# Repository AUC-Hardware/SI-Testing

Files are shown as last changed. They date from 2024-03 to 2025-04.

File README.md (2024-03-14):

# SI-Testing

> Spring 2024, Dr. Shalan

**Goal:** is to provide a circuit capable of testinga chip under changing voltage and temperature. 
- for temperature, we are using a thermoelectric cooler. as a *sub goal* we need to supply with an ideal controlling (PWM) signal to be able to vary the temperature rapidly

---

### Raspberry Pi Pico W

Getting Started: https://projects.raspberrypi.org/en/projects/getting-started-with-the-pico/1

Documentation: https://www.raspberrypi.com/documentation/microcontrollers/raspberry-pi-pico.html

#### Pinout Diagram


Our digital Microcontroller
- Will host ``micropython`` code to execute and control the circuitry
  - The code will have the PID which controlls the PWM signal 

---
### Relay Switch : To be documented

Datasheet:

- is used to protect the Pico from the Temperature varying circuitry
- The PWM signal is suppled to it

---
### Peltier : TEC1-12706

Datasheet: https://www.alldatasheet.com/datasheet-pdf/pdf/227422/ETC2/TEC1-12706.html
> A better datasheet or reference is needed

Thermoelectric cooler
- is used to cary the temperature on the chip
- $12V$, $6A$
- switches heating and cooling sides when current direction is switched 

---
### Digital Potentiometer : MCP4131-103E/P

Datasheet: https://u.pcloud.link/publink/show?code=XZEJx00Z2zHjB7IoRRXOGcCnvikJS4BVzfdy

Volatile Memory Digital Potentiometer
- Is used to vary the voltage on the chip
- Has memory to remember the latest resistance setting

---
### Second Digital Potentiometer : X9C103S

Datasheet: [https://u.pcloud.link/publink/show?code=XZEJx00Z2zHjB7IoRRXOGcCnvikJS4BVzfdy](https://u.pcloud.link/publink/show?code=XZcJRX0ZARyeeIvch2VLE2VBvFsLeyBOw4zV)
Example: https://electropeak.com/learn/interfacing-x9c103s-10k-digital-potentiometer-module-with-arduino/

- Is used to vary the voltage on the chip
- 0-10kΩ with 100 steps
- Up to ±5V across the potentiometer end-points

---
### Temperature Sensor : DS18B20 Waterproof Temperature Sensor

Datasheet: https://u.pcloud.link/publink/show?code=XZfujk0ZSR5hogIrCKkFY19oXnh8zp0lHThX

- Will provide temperature input to the PICO from the Thermoelectric cooler to be given to the PID

---
### Thermometer : TP101 

Datasheet: https://u.pcloud.link/publink/show?code=XZfujk0ZSR5hogIrCKkFY19oXnh8zp0lHThX

- Measuring Temperature Range: -50 to 300 degrees (-58 to 572 Fahrenheit)

---
### Thermometer with probe: TPM-10  

Datasheet: https://u.pcloud.link/publink/show?code=XZfujk0ZSR5hogIrCKkFY19oXnh8zp0lHThX

- Temperature range: -50°C~ 110°C
- Temperature accuracy: ±1°C
- Resolution: 0.1°C

---
### Voltage Regulator: LM317

Datasheet: https://u.pcloud.link/publink/show?code=XZqG0X0ZURodwRRACp8z1VfRVn5GCHM6Uq97

It will be used to assist with voltage control. See the voltage control circuit diagram for more details

---

>[!NOTE] 
>
> Optional circuitry \
> **High Power Resistor**
> - is used to reduce current on the thermoelectric cooler if normal operating current is too high for our need 
> 
> **H-Bridge** 
> - mainly for experimentation 
> - is used to be able to switch the polarity on the thermoelectric cooler so we could switch cooling and heating

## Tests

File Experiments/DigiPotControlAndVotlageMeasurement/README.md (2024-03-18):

Goal was to control Digital Pot according to some condition on the voltage measured
Condition was to break once a certain threshold of voltage was reached

Voltage change was observed with a multimeter and was visually verified by a simple LED.

## Circuit Diagram:



>[!note]
>
> The LED was also fitted in place of the voltage divider (the two resistors)

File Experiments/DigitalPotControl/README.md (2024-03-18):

# Digital Control of X9C103S POT

Aim is to Digitally control the POT and exploring its functionality
The POT has the following control signals,

## Circuit 

Digital_Pot_Control_bb

Skip to [Key Takeaways](#key-takeaways) for a TLDR of X9C103S control.

## Symbol Descriptions

`U/~D` Up Down, control direction of wiper movement

`~INC` increment, negative edge triggered toggling whether wiper will increment or decrement depending on logic of the `U/D` input.

`~CS`Chip Select, Current Counter Value is stored in nonvolatile memory. Once stored the device is put into low power standby until the digital pot control is selected once again.

$V_w$ Wiper output

$V_l$ Low voltage

$V_H$ high voltage

## Mode Selection 

| ~CS| ~INC | U/~D | Mode |
| --- | --- | --- | --- |
| L | Negative Edge | H | Wiper Up |
| L | Negative Edge | L | Wiper Down | 
| Positive Edge | H | X | Store Wiper Position | 
| H | X | X | Standby Current | 
| Positive Edge | L | X | No Store, Return to Standby | 

>[!warning]
>
>Supply Voltage Operational Limits:  $5V\ \pm 10$%

## IMPORTANT: Timings

| Parameter | Min | Typ | Max | Units |
| --- | --- | --- | --- | --- |
| CS to INC setup | 100 | | | ns |
| INC HIGH to U/D change | 100 | | | ns |
| U/D to INC setup | 2.9 | | | $\mu s$ |
| INC LOW period | 1 | | | $\mu s$ | 
| INC HIGH period | 1 | | | $\mu s$ |
| INC Inactive to CS Inactive | 1 | | | $\mu s$ |
| CS deselect time | 20  | | | ms |
| INC to $V_w$ Change | | 100 | 500 | $\mu s$ |
| INC Cycle Time | 4 | | | $\mu s$ |
| INC Rise and Fall Time | | | 500 | $\mu s$ |
| Power Up to Wiper Stable | | | 500 | $\mu s$ |
| $V_{cc}$ Power up Rate | 0.2 | | 50  | $\frac{mV}{\mu S}$|

### Key Takeaways

Operational Voltages
- HIGH: `INC`,`CS`, `U\D` Min: 2V, MAX: VCC + 1
- LOW: `INC`,`CS`, `U\D` Min: -1V, MAX: 0.8

Operational Current
- $I_{CC}$, $V_{CC}$ Active Current, TYP: 1 mA, MAX: 3mA 

#### Wiper Control
Wiper Increments in $101\Omega$
Min Resistance $40\Omega$
Max Resistance $10k\Omega$

Control Signal Timings:
- A sleep for $500 \mu s$ is needed to stabilise the wiper, see ``utimer`` lib for MicroPython
- Changing any of the ``~INC``, ``U/~D`` signals need to occur within $>100ns$ 
- ``INC`` Periods need to last at least for $1 \mu s$
- Any Change to ``U/~D`` is accompanied by a sleep of $2.9 \mu s$
- Maximum Pulse Rate (Cycle time) for ``INC`` is $4 \mu s$

#### Non-Voltatile memory handling

- Any Change to `~CS` needs to last $> 20 ms$ 
- Any Change to ``INC`` after changing `~CS` need to have $100 ns$ delay between them

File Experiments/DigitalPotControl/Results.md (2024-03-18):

- LED gradually goes up in brightness and gradually decreased in brightness

### Important notes

On the Osilliscope the resulting square wave generated from iterating on `blink()` function had a bigger cycle time than expected.

We should change the use of `time` lib and utilise the use of the RP2 assembly to have acute control over the delay.

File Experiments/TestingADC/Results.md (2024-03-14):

# PicoADCTest

## Description

This was a simple experiment to test the PICO's ability to read an analog signal that ranges from 0 to 3.3V  (due to using the PICO's Vcc)

ADC has a 12-bit resolution, which means a range from 0 to 4095
In micro python this is mapped to a 16-bit value, which means the code wise it will range from 0 to 65535

## Method

Using ADC on pin 31 (GP 26), read voltage across a 10k Ohm mechanical potentiometer and compare readings to that of a multimeter.

## Results

PICO was able to accuratly read voltage such that it always matched the readings on our digital multimeter ( the M890G ).

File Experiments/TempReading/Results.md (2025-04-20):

# DS18B20 Temprature reading experiment

## Description

This was a simple experiment to test the reading of the temprature from the DS18B20 temprature sensor to the pico microcontroller.

## Method

The libraries used was the onewire library and the DS18x20 library. Together, we are able to interface our DS18B20 device and read temprature from it. The pin used to read temprature was PIN 15, which was connected to the DQ on the temprature sensor. VDD was supplied from the pico as 3.3V and GND was also from the pico.

## Results

PICO was able to accuratly read temprature.

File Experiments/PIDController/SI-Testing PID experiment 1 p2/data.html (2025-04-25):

| A | B | C | D | E | F | G | H
1 | PID Out | | Time 40ms | Measured Temperature | Set point | | Parameters Used | Parameter Value
2 | 38.9898 | | 1 | 30 | 40 | | Kp | 1
3 | 38.99355 | | 2 | 30 | 40 | | Ki | 2
4 | 42.30204 | | 3 | 30 | 40 | | Kd | 1
5 | 47.70129 | | 4 | 30 | 40
6 | 53.92326 | | 5 | 30 | 40 | | Sampling rate (seconds) | 0.45
7 | 52.48206 | | 6 | 30 | 40 | | tau | 1
8 | 51.57029 | | 7 | 30 | 40
9 | 50.99345 | | 8 | 30 | 40 | | integral anti windup max value | -50
10 | 50.62851 | | 9 | 30 | 40 | | integral anti windup min value | 50
11 | 50.39762 | | 10 | 30 | 40
12 | 50.25156 | | 11 | 30 | 40 | | Starting PID output | 23
13 | 50.15915 | | 12 | 30 | 40
14 | 50.10069 | | 13 | 30 | 40
15 | 50.0637 | | 14 | 30 | 40
16 | 50.0403 | | 15 | 30 | 40 | | Max Oscillation Temp | 42.6875
17 | 50.0255 | | 16 | 30 | 40 | | Min Oscillation Temp | 39.0625
18 | 50.01613 | | 17 | 30 | 40
19 | 50.0102 | | 18 | 30 | 40
20 | 50.00645 | | 19 | 30 | 40
21 | 49.90204 | | 20 | 29.875 | 40
22 | 49.93803 | | 21 | 29.875 | 40
23 | 49.96079 | | 22 | 29.875 | 40
24 | 49.9752 | | 23 | 29.875 | 40
25 | 49.98431 | | 24 | 29.875 | 40
26 | 49.99007 | | 25 | 29.875 | 40
27 | 49.99372 | | 26 | 29.875 | 40
28 | 49.99603 | | 27 | 29.875 | 40
29 | 49.99749 | | 28 | 29.875 | 40
30 | 49.99841 | | 29 | 29.875 | 40
31 | 49.99899 | | 30 | 29.875 | 40
32 | 49.99936 | | 31 | 29.875 | 40
33 | 49.9996 | | 32 | 29.875 | 40
34 | 49.99974 | | 33 | 29.875 | 40
35 | 49.99984 | | 34 | 29.875 | 40
36 | 49.9999 | | 35 | 29.875 | 40
37 | 49.99994 | | 36 | 29.875 | 40
38 | 49.99996 | | 37 | 29.875 | 40
39 | 49.99997 | | 38 | 29.875 | 40
40 | 49.99998 | | 39 | 29.875 | 40
41 | 49.99999 | | 40 | 29.875 | 40
42 | 49.99999 | | 41 | 29.875 | 40
43 | 50 | | 42 | 29.875 | 40
44 | 50 | | 43 | 29.875 | 40
45 | 50 | | 44 | 29.875 | 40
46 | 50 | | 45 | 29.875 | 40
47 | 50 | | 46 | 29.875 | 40
48 | 50 | | 47 | 29.875 | 40
49 | 50 | | 48 | 29.875 | 40
50 | 50 | | 49 | 29.875 | 40
51 | 50 | | 50 | 29.875 | 40
52 | 50 | | 51 | 29.875 | 40
53 | 50 | | 52 | 29.875 | 40
54 | 50 | | 53 | 29.875 | 40
55 | 50 | | 54 | 29.875 | 40
56 | 50 | | 55 | 29.875 | 40
57 | 50 | | 56 | 29.875 | 40
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

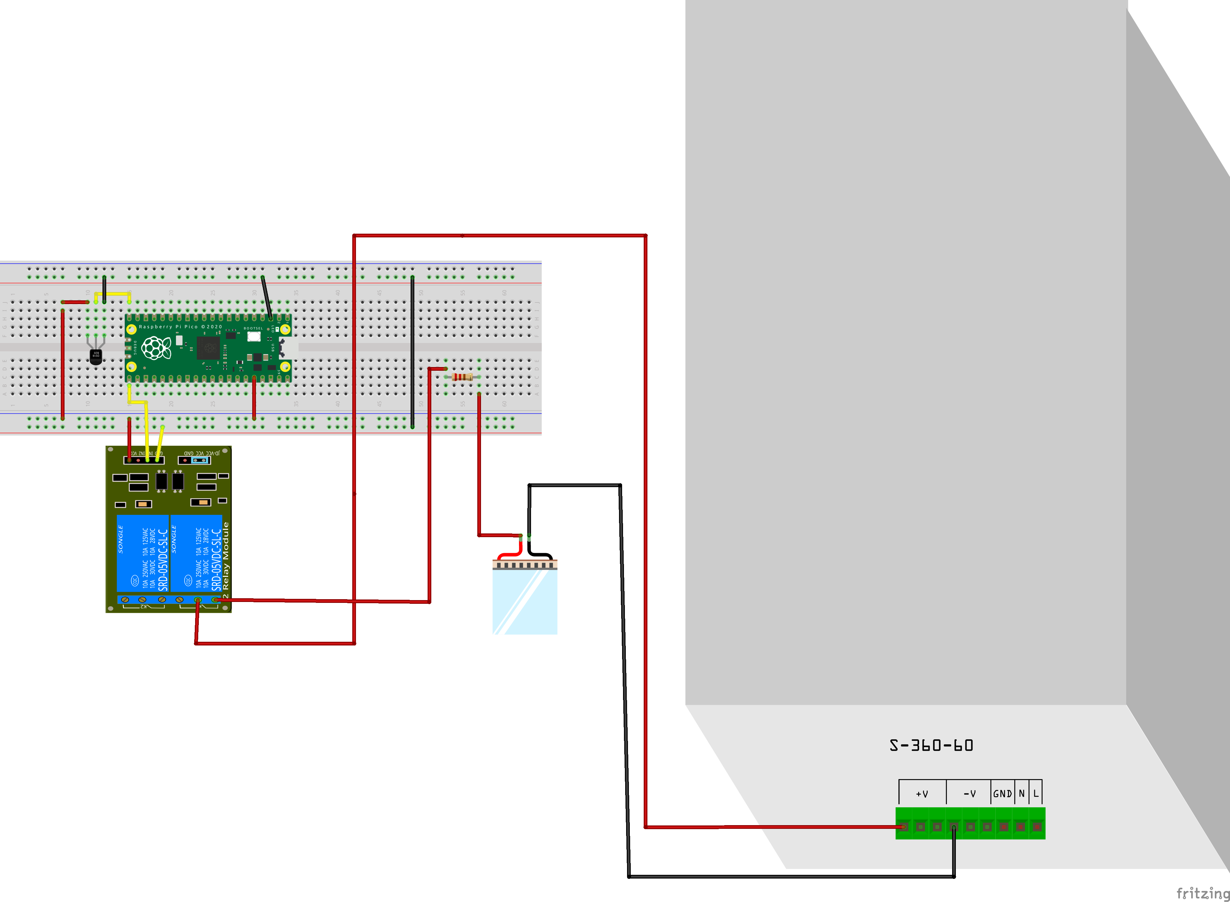
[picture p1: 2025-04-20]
Experiments/Temp_reading_relay_loop/relay_peltier_tempsensor_loop.png

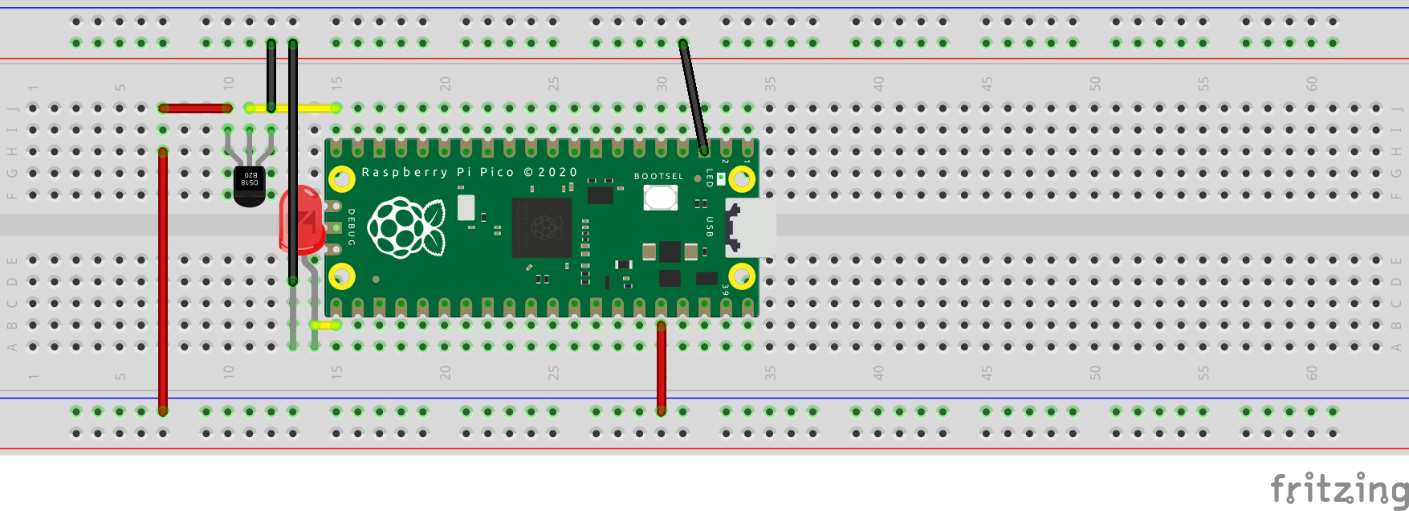
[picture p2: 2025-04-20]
Experiments/TempReading/Temprature_reading_DS18B20_diagram.png

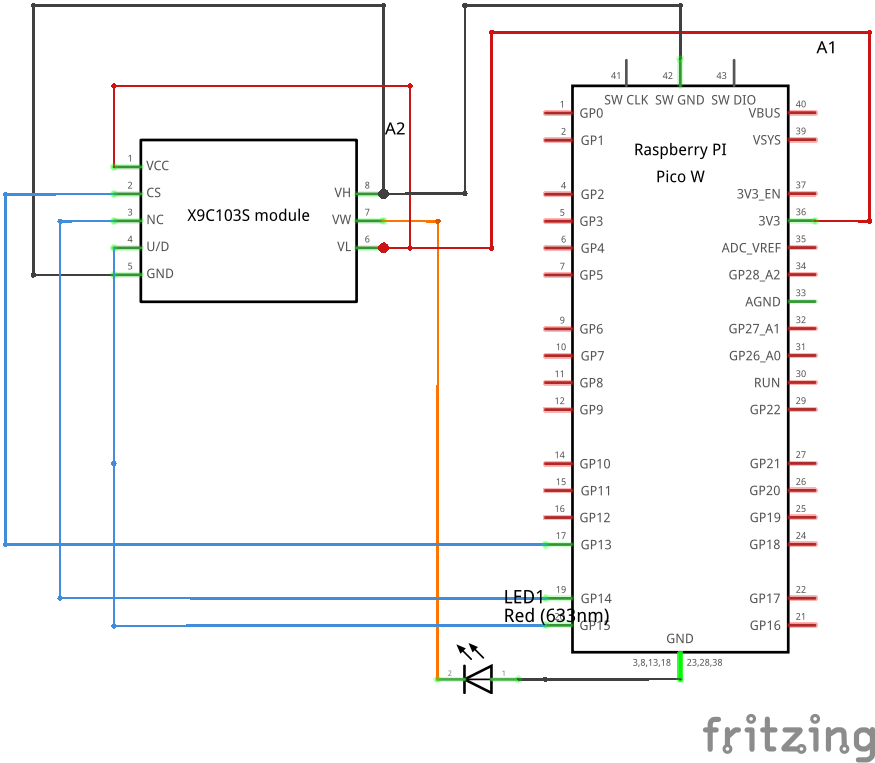
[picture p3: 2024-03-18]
Experiments/DigitalPotControl/Digital_Pot_Control_schem.png

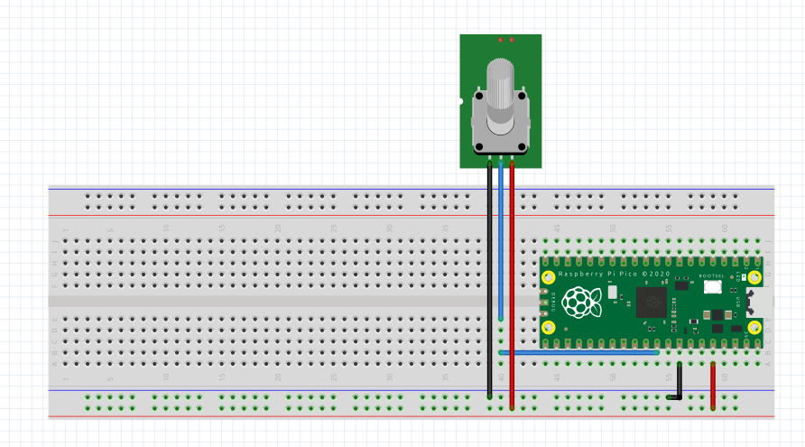
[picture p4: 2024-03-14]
Experiments/TestingADC/PicoADCTest.png

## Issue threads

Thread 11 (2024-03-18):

Complete Digital Signal Control using RP2 Assembly

Ahmed-Waseem77, 2024-03-18:
uncovered in issue #8

---

When generating signals any two successive toggles for a PIO pin has about 20 us ON (or OFF) period, (This was verified with an oscilloscope).

For our use case we would need greater control in ns scale for greater efficiency thus the need for RP2 assembly digital signal controllers.

Goal is to construct a general class or a function for digital signal generation in us.
RP2 has around 125MHZ so the cycle takes around 8ns.

shalan, 2024-03-18:
Not sure about the need for this.
The process we are controlling is slow; there is no need for us DIO resolution.

Ahmed-Waseem77, 2024-03-21:
Noted, closing the issue!

Closed 2024-03-21.

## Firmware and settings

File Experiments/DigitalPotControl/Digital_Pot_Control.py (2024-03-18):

from machine import Pin
import time
import rp2

# CS to INC setup
def tci():
    time.sleep_ms(5)

# UD to INC setup
def tdi():
    time.sleep_us(5)

# INC High to UD change
def tid():
    time.sleep_us(5)
    
# INC High and Low period
def tihl():
    #5 microseconds
    time.sleep_us(5)

# chip select
cs = Pin(14,mode=Pin.OUT,value=0)
tci()

# up down
ud = Pin(13,mode=Pin.OUT,value=1)
tdi()

# increment
inc = Pin(12,mode=Pin.OUT,value=1)
tid()


# This yields a pulse of 35 us which is counter intuitive
# for the time being this suits our use case
# TODO: change this into rp2 assembly instructions
def blink(pin):
    pin.toggle()
    tihl()
    
def wiperControl(increments,updownSelect):
    ud.value(updownSelect)
    tdi()
    for i in range(0,increments):
        time.sleep_ms(2)
        blink(inc)
        
        
#10k ohms and 101ohm step
#100 increments to max/min
#for some odd reason, it maxes out at ~110 not 100
while True:
    wiperControl(110,1)
    wiperControl(110,0)

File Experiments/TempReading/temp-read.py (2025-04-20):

from machine import Pin
import time
import onewire
import ds18x20

ow = onewire.OneWire(Pin(15))
ds = ds18x20.DS18X20(ow)
p15 = Pin(16, Pin.OUT)


devices = ds.scan()
print('found devices:', devices)

while True:
    ds.convert_temp()
    time.sleep_ms(750)
    temp = ds.read_temp(devices[0])
    if(temp > 30.0):
        p15.value(1)
    else:
        p15.value(0)
        
    for device in devices:
        print("Device: {}".format(device))
        
        print("Temperature= {}".format(ds.read_temp(device)))

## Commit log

2024-02-29 Update README.md
    Circuit Schematic image
2024-03-07 Adds PicoADCTest Diagram + Descriptions
    [PicoADCTest.fzz]
2024-03-07 Update README.md
    Adds temp sensor documentation
2024-03-15 Digital Pot Control Fritz, schematic
    [Digital_Pot_Control.fzz]
2024-03-15 removing empty note from circuit diagram
2024-03-17 code and documentation (needs schematic)
2024-03-17 Update README.md
    schematic, note
2024-03-18 added results and schematics
2024-03-19 modified schematic
2025-04-22 Temperature reading loop
2025-04-24 pid control functionality (untested)
2025-04-25 Working PID and First Test Data
    [data.csv]
2025-04-26 PID Tuning
    [data.csv]
